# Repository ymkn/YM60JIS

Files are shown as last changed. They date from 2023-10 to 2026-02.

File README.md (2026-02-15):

# YM60JIS

A hot-swappable 60% mechanical keyboard PCB with Japanese (JIS) layout, powered by the RP2040 microcontroller. It is compatible with most Poker and GH60-style 60% keyboard cases.

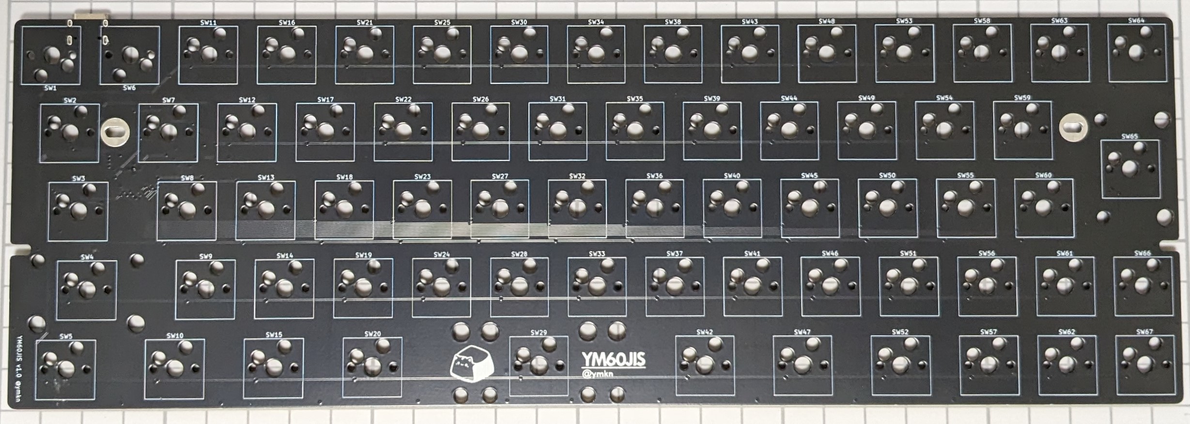
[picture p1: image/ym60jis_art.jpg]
YM60JIS Art


## Default Layout / Key Mapping

Customize your key mapping from the default shown below using the [Vial](https://get.vial.today/) configurator.

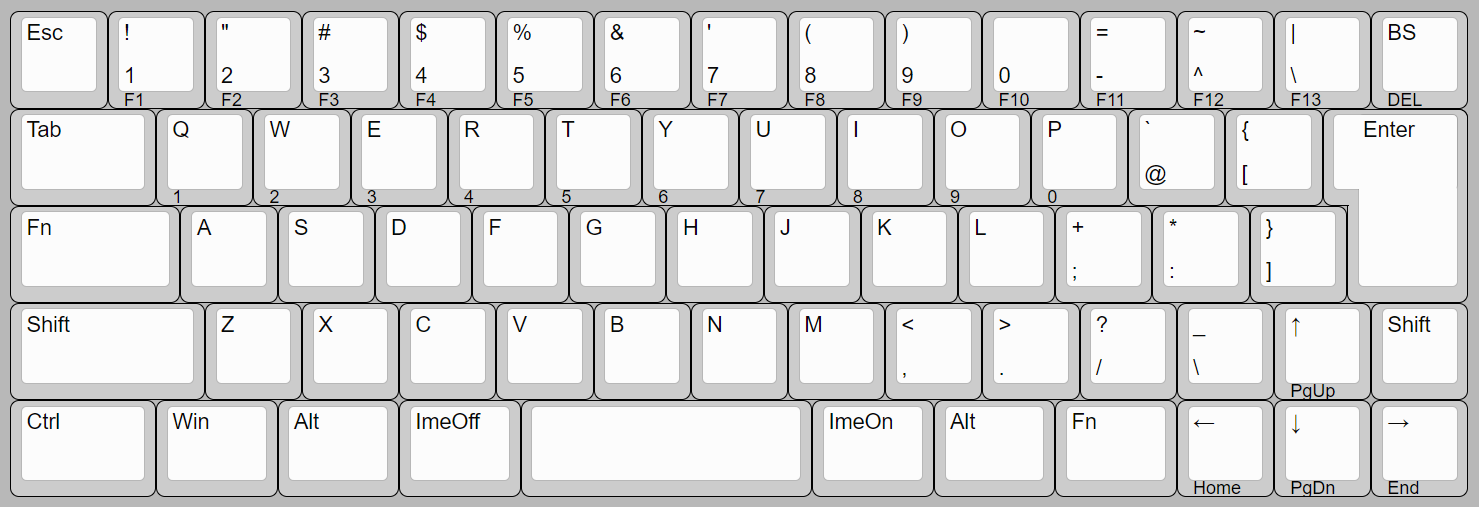
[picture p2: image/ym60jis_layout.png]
YM60JIS Layout


Supports 3u spacebar (requires 3u stabilizers) or 2.25u/2.75u spacebar with 2u stabilizers.

## Specification

- Supports Cherry MX-style switches
- USB Type-C connector (USB 2.0)
- Hot-swap sockets for mechanical switches
- Dimensions: 285 × 94.6 × 1.6 mm (W × H × D)
- Compatible with most 60% keyboard cases
  - Note: Center and right bottom mounting holes are not included

## Build Guide

See [doc/buildguide.md](doc/buildguide.md)

## LICENSE

This project is licensed under the MIT License, see the [LICENSE file](LICENSE) for details.

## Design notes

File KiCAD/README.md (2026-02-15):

# KiCAD source files

## Requirements

KiCAD 8.x or higher

## Dependencies

### Package Manager Libraries

Install the following library from KiCAD Package Manager:

- marbastlib (https://github.com/ebastler/marbastlib)
  - Install via the external ebastler KiCAD repository or from file

### External libraries

The following libraries are included as submodules:

- kleeb (https://github.com/crides/kleeb)
  - Components: rp2040-zero
- KiCAD_FootPrint (https://github.com/Salicylic-acid3/KiCAD_FootPrint)
  - Components: Keyswitch hole, stabilizer hole
- gh60 (https://github.com/komar007/gh60)
  - Components: Mounting hole

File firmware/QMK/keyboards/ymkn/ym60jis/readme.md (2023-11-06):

# ymkn/ym60jis

YM60JIS - A JIS layout 60% hot swappable custom mechanical keyboard PCB powered by RP2040.

* Keyboard Maintainer: [ymkn](https://github.com/ymkn)

Make example for this keyboard (after setting up your build environment):

    make ymkn/ym60jis:vial

Flashing example for this keyboard:

1. Enter the bootloader.
2. Simply copy ymkn_ym60jis_vial.uf2 to RPI_RP2 drive.

This keyboard supports [Vial](https://get.vial.today/) configurator.

## Bootloader

Enter the bootloader in 2 ways:

* **Bootmagic reset**: Hold down the key at (0,0) in the matrix (usually the top left key or Escape) and plug in the keyboard
* **Physical reset button**: Briefly press the button on the back of the PCB - some may have pads you must short instead

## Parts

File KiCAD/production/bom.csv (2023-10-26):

Designator | Footprint | Quantity | Value | LCSC Part #
BTN1 | SW_Push_1P1T_XKB_TS-1187A | 1 | TS-1187A-B-A-B
C1, C2 | 0402 | 2 | 10uF
C10, C13, C16, C17, C3, C4, C5, C6, C7, C8, C9 | 0402 | 11 | 100nF
C11, C12 | 0402 | 2 | 1uF
C14, C15 | 0402 | 2 | 20pF
D1, D10, D11, D12, D13, D14, D15, D16, D17, D18, D19, D2, D20, D21, D22, D23, D24, D25, D26, D27, D28, D29, D3, D30, D31, D32, D33, D34, D35, D36, D37, D38, D39, D4, D40, D41, D42, D43, D44, D45, D46, D47, D48, D49, D5, D50, D51, D52, D53, D54, D55, D56, D57, D58, D59, D6, D60, D61, D62, D63, D64, D65, D66, D67, D7, D8, D9 | D_SOD-123 | 67 | 1N4148W
J1 | USB_C_Receptacle_HRO_TYPE-C-31-M-12 | 1 | TYPE-C-31-M-12
R1, R3 | 0402 | 2 | 5.1K
R4, R5 | 0603 | 2 | 27
R6 | 0402 | 1 | 1KΩ
R7 | 0402 | 1 | 10kΩ
R8 | 0402 | 1 | 1K
SW1, SW11, SW12, SW13, SW14, SW16, SW17, SW18, SW19, SW21, SW22, SW23, SW24, SW25, SW26, SW27, SW28, SW30, SW31, SW32, SW33, SW34, SW35, SW36, SW37, SW38, SW39, SW40, SW41, SW43, SW44, SW45, SW46, SW48, SW49, SW50, SW51, SW53, SW54, SW55, SW56, SW57, SW58, SW59, SW6, SW60, SW61, SW62, SW66, SW67, SW7, SW8, SW9 | SW_Hotswap_Kailh_MX_1.00u | 53 | SW_Push
SW10, SW15, SW20, SW42, SW47, SW52 | SW_Hotswap_Kailh_MX_1.25u | 6 | SW_Push
SW2, SW5 | SW_Hotswap_Kailh_MX_1.50u | 2 | SW_Push
SW29 | SW_Hotswap_Kailh_MX_3.00u | 1 | Space
SW3 | SW_Hotswap_Kailh_MX_1.75u | 1 | SW_Push
SW4 | SW_Hotswap_Kailh_MX_2.00u | 1 | SW_Push
SW63 | SW_Hotswap_Kailh_MX_1.00u | 1 | Yen
SW64 | SW_Hotswap_Kailh_MX_1.00u | 1 | Backspace
SW65 | SW_Hotswap_Kailh_MX_ISOEnter | 1 | ISOEnter
U1 | SOT-23-3 | 1 | XC6206P332MR
U2 | SOT-363-6_2P2X1P35_ONS | 1 | SMF05CT1G
U3 | QFN-56-1EP_7x7mm_P0.4mm_EP3.2x3.2mm | 1 | RP2040
U4 | W25Q16JVUXIQ_WIN | 1 | W25Q16JVUXIQ
Y1 | Crystal_SMD_3225-4Pin_3.2x2.5mm | 1 | X322512MSB4SI

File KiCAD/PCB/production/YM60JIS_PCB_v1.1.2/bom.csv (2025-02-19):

Designator | Footprint | Quantity | Value | LCSC Part #
BTN1 | SW_Push_1P1T_XKB_TS-1187A | 1 | TS-1187A-B-A-B | C318884
C1, C2 | 0402 | 2 | 10uF | C15525
C10, C13, C16, C17, C3, C4, C5, C6, C7, C8, C9 | 0402 | 11 | 100nF | C1525
C11, C12 | 0402 | 2 | 1uF | C52923
C14, C15 | 0402 | 2 | 20pF | C1554
D1, D10, D11, D12, D13, D14, D15, D16, D17, D18, D19, D2, D20, D21, D22, D23, D24, D25, D26, D27, D28, D29, D3, D30, D31, D32, D33, D34, D35, D36, D37, D38, D39, D4, D40, D41, D42, D43, D44, D45, D46, D47, D48, D49, D5, D50, D51, D52, D53, D54, D55, D56, D57, D58, D59, D6, D60, D61, D62, D63, D64, D65, D66, D67, D7, D8, D9 | D_SOD-123 | 67 | 1N4148W | C81598
J1 | USB_C_Receptacle_HRO_TYPE-C-31-M-12 | 1 | TYPE-C-31-M-12 | C165948
R1, R3 | 0402 | 2 | 5.1K | C25905
R4, R5 | 0603 | 2 | 27 | C25190
R6 | 0402 | 1 | 1KΩ | C11702
R7 | 0402 | 1 | 10kΩ | C25744
R8 | 0402 | 1 | 1K | C11702
SW1, SW11, SW12, SW13, SW14, SW16, SW17, SW18, SW19, SW21, SW22, SW23, SW24, SW25, SW26, SW27, SW28, SW30, SW31, SW32, SW33, SW34, SW35, SW36, SW37, SW38, SW39, SW4, SW40, SW41, SW42, SW43, SW44, SW45, SW46, SW48, SW49, SW50, SW51, SW53, SW54, SW55, SW56, SW57, SW58, SW59, SW6, SW60, SW61, SW62, SW66, SW67, SW7, SW8, SW9 | SW_MX_HS_CPG151101S11_1u | 55 | SW_Push | C41430893
SW10, SW15, SW20, SW47, SW52 | SW_MX_HS_CPG151101S11_1.25u | 5 | SW_Push | C41430893
SW2, SW5 | SW_MX_HS_CPG151101S11_1.5u | 2 | SW_Push | C41430893
SW29 | SW_MX_HS_CPG151101S11_1u | 1 | Space | C41430893
SW3 | SW_MX_HS_CPG151101S11_1.75u | 1 | SW_Push | C41430893
SW63 | SW_MX_HS_CPG151101S11_1u | 1 | Yen | C41430893
SW64 | SW_MX_HS_CPG151101S11_1u | 1 | Backspace | C41430893
SW65 | SW_MX_HS_CPG151101S11_1u | 1 | ISOEnter | C41430893
U1 | SOT-23-3 | 1 | XC6206P332MR | C5446
U2 | SOT-363-6_2P2X1P35_ONS | 1 | SMF05CT1G | C15879
U3 | QFN-56-1EP_7x7mm_P0.4mm_EP3.2x3.2mm | 1 | RP2040 | C2040
U4 | W25Q16JVUXIQ_WIN | 1 | W25Q16JVUXIQ | C2843335
Y1 | Crystal_SMD_3225-4Pin_3.2x2.5mm | 1 | X322512MSB4SI | C9002

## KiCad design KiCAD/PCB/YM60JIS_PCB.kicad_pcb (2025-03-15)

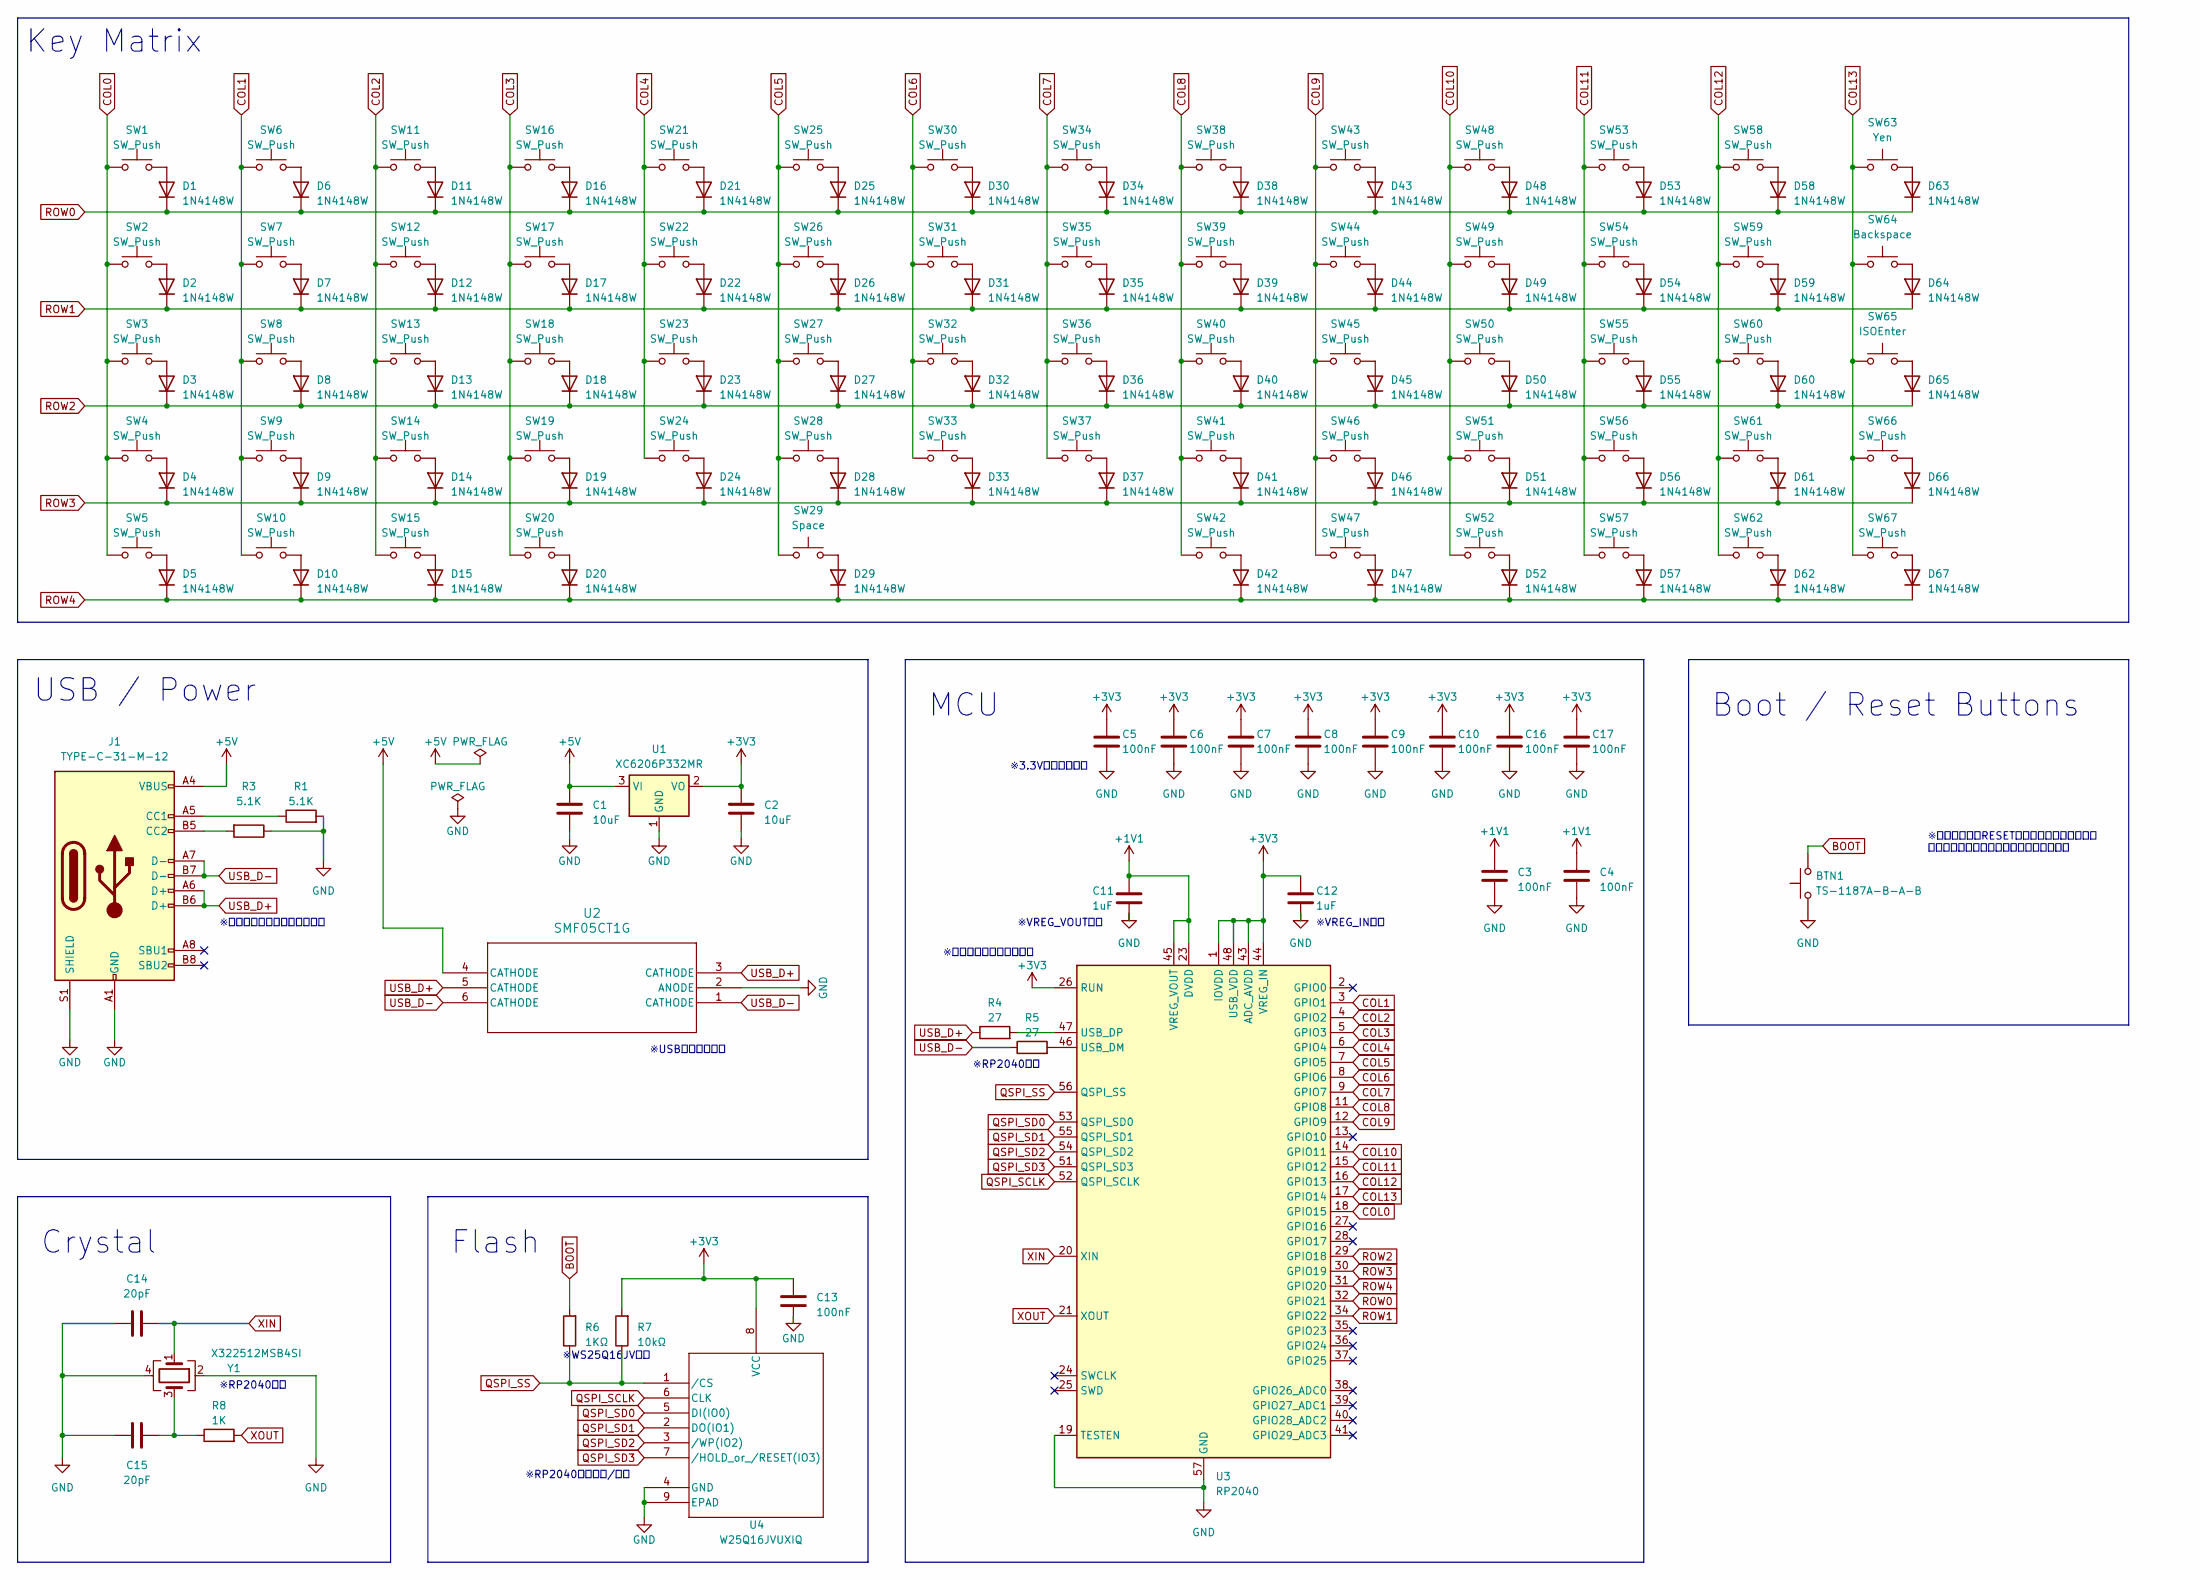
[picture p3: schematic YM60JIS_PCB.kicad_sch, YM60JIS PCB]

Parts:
BTN1: TS-1187A-B-A-B; SW_Push_1P1T_XKB_TS-1187A; JLCPCB Part # C318884
C1, C2: 10uF; C_0402_1005Metric; JLCPCB Part # C15525
C3, C4, C5, C6, C7, C8, C9, C10, C13, C16, C17: 100nF; C_0402_1005Metric; JLCPCB Part # C1525
C11, C12: 1uF; C_0402_1005Metric; JLCPCB Part # C52923
C14, C15: 20pF; C_0402_1005Metric; JLCPCB Part # C1554
D1, D2, D3, D4, D5, D6, D7, D8, D9, D10, D11, D12, D13, D14, D15, D16, D17, D18, D19, D20, D21, D22, D23, D24, D25, D26, D27, D28, D29, D30, D31, D32, D33, D34, D35, D36, D37, D38, D39, D40, D41, D42, D43, D44, D45, D46, D47, D48, D49, D50, D51, D52, D53, D54, D55, D56, D57, D58, D59, D60, D61, D62, D63, D64, D65, D66, D67: 1N4148W; D_SOD-123; JLCPCB Part # C81598
J1: TYPE-C-31-M-12; USB_C_Receptacle_HRO_TYPE-C-31-M-12; JLCPCB Part # C165948
R1, R3: 5.1K; R_0402_1005Metric; JLCPCB Part # C25905
R4, R5: 27; R_0603_1608Metric; JLCPCB Part # C25190
R6: 1KΩ; R_0402_1005Metric; JLCPCB Part # C11702
R7: 10kΩ; R_0402_1005Metric; JLCPCB Part # C25744
R8: 1K; R_0402_1005Metric; JLCPCB Part # C11702
SW1, SW4, SW6, SW7, SW8, SW9, SW11, SW12, SW13, SW14, SW16, SW17, SW18, SW19, SW21, SW22, SW23, SW24, SW25, SW26, SW27, SW28, SW30, SW31, SW32, SW33, SW34, SW35, SW36, SW37, SW38, SW39, SW40, SW41, SW42, SW43, SW44, SW45, SW46, SW48, SW49, SW50, SW51, SW53, SW54, SW55, SW56, SW57, SW58, SW59, SW60, SW61, SW62, SW66, SW67: SW_Push; SW_MX_HS_CPG151101S11_1u; JLCPCB Part # C41430893
SW2, SW5: SW_Push; SW_MX_HS_CPG151101S11_1.5u; JLCPCB Part # C41430893
SW3: SW_Push; SW_MX_HS_CPG151101S11_1.75u; JLCPCB Part # C41430893
SW10, SW15, SW20, SW47, SW52: SW_Push; SW_MX_HS_CPG151101S11_1.25u; JLCPCB Part # C41430893
SW29: Space; SW_MX_HS_CPG151101S11_1u; JLCPCB Part # C41430893
SW63: Yen; SW_MX_HS_CPG151101S11_1u; JLCPCB Part # C41430893
SW64: Backspace; SW_MX_HS_CPG151101S11_1u; JLCPCB Part # C41430893
SW65: ISOEnter; SW_MX_HS_CPG151101S11_1u; JLCPCB Part # C41430893
U1: XC6206P332MR; SOT-23-3; JLCPCB Part # C5446
U2: SMF05CT1G; SOT-363-6_2P2X1P35_ONS; JLCPCB Rotation Offset 180
U3: RP2040; QFN-56-1EP_7x7mm_P0.4mm_EP3.2x3.2mm; JLCPCB Part # C2040
U4: W25Q16JVUXIQ; W25Q16JVUXIQ_WIN; JLCPCB Rotation Offset 90
Y1: X322512MSB4SI; Crystal_SMD_3225-4Pin_3.2x2.5mm; JLCPCB Part # C9002

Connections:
+1V1: C3.1, C4.1, C11.1, U3.23 (DVDD), U3.45 (VREG_VOUT), U3.50 (DVDD)
+3V3: C2.1, C5.1, C6.1, C7.1, C8.1, C9.1, C10.1, C12.1, C13.1, C16.1, C17.1, R7.2, U1.2 (VO), U3.1 (IOVDD), U3.10 (IOVDD), U3.22 (IOVDD), U3.26 (RUN), U3.33 (IOVDD), U3.42 (IOVDD), U3.43 (ADC_AVDD), U3.44 (VREG_IN), U3.48 (USB_VDD), U3.49 (IOVDD), U4.8 (VCC)
+5V: C1.1, J1.A4 (VBUS), J1.A9 (VBUS), J1.B4 (VBUS), J1.B9 (VBUS), U1.3 (VI), U2.4 (CATHODE)
BOOT: BTN1.2, R6.2
COL0: SW1.1, SW2.1, SW3.1, SW4.1, SW5.1, U3.18 (GPIO15)
COL1: SW6.1, SW7.1, SW8.1, SW9.1, SW10.1, U3.3 (GPIO1)
COL2: SW11.1, SW12.1, SW13.1, SW14.1, SW15.1, U3.4 (GPIO2)
COL3: SW16.1, SW17.1, SW18.1, SW19.1, SW20.1, U3.5 (GPIO3)
COL4: SW21.1, SW22.1, SW23.1, SW24.1, U3.6 (GPIO4)
COL5: SW25.1, SW26.1, SW27.1, SW28.1, SW29.1, U3.7 (GPIO5)
COL6: SW30.1, SW31.1, SW32.1, SW33.1, U3.8 (GPIO6)
COL7: SW34.1, SW35.1, SW36.1, SW37.1, U3.9 (GPIO7)
COL8: SW38.1, SW39.1, SW40.1, SW41.1, SW42.1, U3.11 (GPIO8)
COL9: SW43.1, SW44.1, SW45.1, SW46.1, SW47.1, U3.12 (GPIO9)
COL10: SW48.1, SW49.1, SW50.1, SW51.1, SW52.1, U3.14 (GPIO11)
COL11: SW53.1, SW54.1, SW55.1, SW56.1, SW57.1, U3.15 (GPIO12)
COL12: SW58.1, SW59.1, SW60.1, SW61.1, SW62.1, U3.16 (GPIO13)
COL13: SW63.1, SW64.1, SW65.1, SW66.1, SW67.1, U3.17 (GPIO14)
GND: BTN1.1, C1.2, C2.2, C3.2, C4.2, C5.2, C6.2, C7.2, C8.2, C9.2, C10.2, C11.2, C12.2, C13.2, C14.1, C15.1, C16.2, C17.2, J1.A1 (GND), J1.A12 (GND), J1.B1 (GND), J1.B12 (GND), J1.S1 (SHIELD), R1.2, R3.1, U1.1 (GND), U2.2 (ANODE), U3.19 (TESTEN), U3.57 (GND), U4.4 (GND), U4.9 (EPAD), Y1.2, Y1.4
unnamed: C15.2, R8.1, Y1.3
unnamed: D1.2 (A), SW1.2
unnamed: D2.2 (A), SW2.2
unnamed: D3.2 (A), SW3.2
unnamed: D4.2 (A), SW4.2
unnamed: D5.2 (A), SW5.2
unnamed: D6.2 (A), SW6.2
unnamed: D7.2 (A), SW7.2
unnamed: D8.2 (A), SW8.2
unnamed: D9.2 (A), SW9.2
unnamed: D10.2 (A), SW10.2
unnamed: D11.2 (A), SW11.2
unnamed: D12.2 (A), SW12.2
unnamed: D13.2 (A), SW13.2
unnamed: D14.2 (A), SW14.2
unnamed: D15.2 (A), SW15.2
unnamed: D16.2 (A), SW16.2
unnamed: D17.2 (A), SW17.2
unnamed: D18.2 (A), SW18.2
unnamed: D19.2 (A), SW19.2
unnamed: D20.2 (A), SW20.2
unnamed: D21.2 (A), SW21.2
unnamed: D22.2 (A), SW22.2
unnamed: D23.2 (A), SW23.2
unnamed: D24.2 (A), SW24.2
unnamed: D25.2 (A), SW25.2
unnamed: D26.2 (A), SW26.2
unnamed: D27.2 (A), SW27.2
unnamed: D28.2 (A), SW28.2
unnamed: D29.2 (A), SW29.2
unnamed: D30.2 (A), SW30.2
unnamed: D31.2 (A), SW31.2
unnamed: D32.2 (A), SW32.2
unnamed: D33.2 (A), SW33.2
unnamed: D34.2 (A), SW34.2
unnamed: D35.2 (A), SW35.2
unnamed: D36.2 (A), SW36.2
unnamed: D37.2 (A), SW37.2
unnamed: D38.2 (A), SW38.2
unnamed: D39.2 (A), SW39.2
unnamed: D40.2 (A), SW40.2
unnamed: D41.2 (A), SW41.2
unnamed: D42.2 (A), SW42.2
unnamed: D43.2 (A), SW43.2
unnamed: D44.2 (A), SW44.2
unnamed: D45.2 (A), SW45.2
unnamed: D46.2 (A), SW46.2
unnamed: D47.2 (A), SW47.2
unnamed: D48.2 (A), SW48.2
unnamed: D49.2 (A), SW49.2
unnamed: D50.2 (A), SW50.2
unnamed: D51.2 (A), SW51.2
unnamed: D52.2 (A), SW52.2
unnamed: D53.2 (A), SW53.2
unnamed: D54.2 (A), SW54.2
unnamed: D55.2 (A), SW55.2
unnamed: D56.2 (A), SW56.2
unnamed: D57.2 (A), SW57.2
unnamed: D58.2 (A), SW58.2
unnamed: D59.2 (A), SW59.2
unnamed: D60.2 (A), SW60.2
unnamed: D61.2 (A), SW61.2
unnamed: D62.2 (A), SW62.2
unnamed: D63.2 (A), SW63.2
unnamed: D64.2 (A), SW64.2
unnamed: D65.2 (A), SW65.2
unnamed: D66.2 (A), SW66.2
unnamed: D67.2 (A), SW67.2
unnamed: J1.A5 (CC1), R1.1
unnamed: J1.B5 (CC2), R3.2
unnamed: R5.2, U3.46 (USB_DM)
unnamed: R4.2, U3.47 (USB_DP)
QSPI_SCLK: U3.52 (QSPI_SCLK), U4.6 (CLK)
QSPI_SD0: U3.53 (QSPI_SD0), U4.5 (DI(IO0))
QSPI_SD1: U3.55 (QSPI_SD1), U4.2 (DO(IO1))
QSPI_SD2: U3.54 (QSPI_SD2), U4.3 (/WP(IO2))
QSPI_SD3: U3.51 (QSPI_SD3), U4.7 (/HOLD_or_/RESET(IO3))
QSPI_SS: R6.1, R7.1, U3.56 (QSPI_SS), U4.1 (/CS)
ROW0: D1.1 (K), D6.1 (K), D11.1 (K), D16.1 (K), D21.1 (K), D25.1 (K), D30.1 (K), D34.1 (K), D38.1 (K), D43.1 (K), D48.1 (K), D53.1 (K), D58.1 (K), D63.1 (K), U3.32 (GPIO21)
ROW1: D2.1 (K), D7.1 (K), D12.1 (K), D17.1 (K), D22.1 (K), D26.1 (K), D31.1 (K), D35.1 (K), D39.1 (K), D44.1 (K), D49.1 (K), D54.1 (K), D59.1 (K), D64.1 (K), U3.34 (GPIO22)
ROW2: D3.1 (K), D8.1 (K), D13.1 (K), D18.1 (K), D23.1 (K), D27.1 (K), D32.1 (K), D36.1 (K), D40.1 (K), D45.1 (K), D50.1 (K), D55.1 (K), D60.1 (K), D65.1 (K), U3.29 (GPIO18)
ROW3: D4.1 (K), D9.1 (K), D14.1 (K), D19.1 (K), D24.1 (K), D28.1 (K), D33.1 (K), D37.1 (K), D41.1 (K), D46.1 (K), D51.1 (K), D56.1 (K), D61.1 (K), D66.1 (K), U3.30 (GPIO19)
ROW4: D5.1 (K), D10.1 (K), D15.1 (K), D20.1 (K), D29.1 (K), D42.1 (K), D47.1 (K), D52.1 (K), D57.1 (K), D62.1 (K), D67.1 (K), U3.31 (GPIO20)
USB_D+: J1.A6 (D+), J1.B6 (D+), R4.1, U2.3 (CATHODE), U2.5 (CATHODE)
USB_D-: J1.A7 (D-), J1.B7 (D-), R5.1, U2.1 (CATHODE), U2.6 (CATHODE)
XIN: C14.2, U3.20 (XIN), Y1.1
XOUT: R8.2, U3.21 (XOUT)

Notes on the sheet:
※RP2040近傍
Flash
Key Matrix
※リセットボタン実装無し
USB / Power
※WS25Q16JV近傍
※USBコネクタ近傍
※差動信号、配線長さ合わせる
※VREG_IN近傍
Boot / Reset Buttons
MCU
※3.3V電源ピン近傍
※RP2040近傍配置/直結
※VREG_VOUT近傍
Crystal
※以前はここにRESETボタンの回路があった。 基板スペースと費用の都合で削除した。

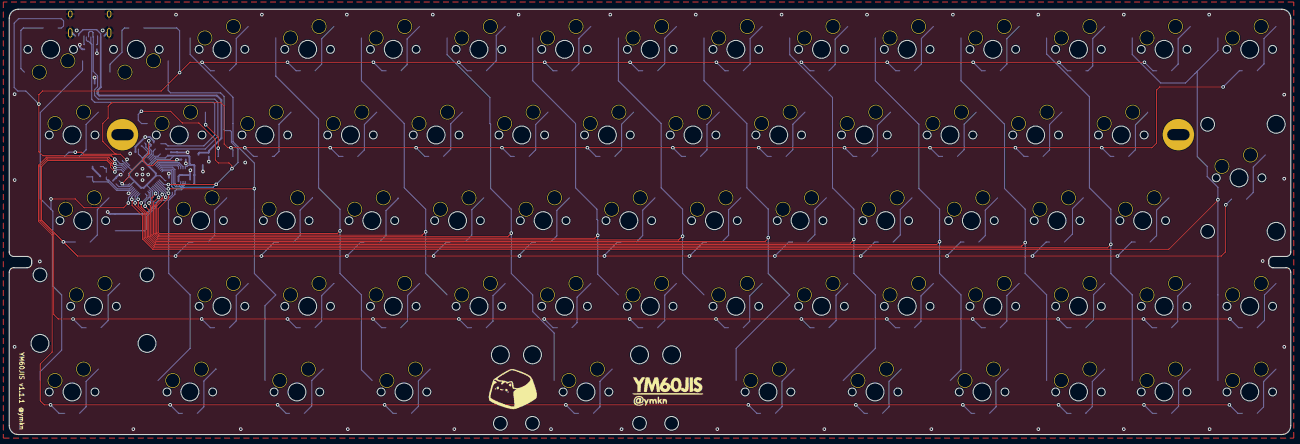
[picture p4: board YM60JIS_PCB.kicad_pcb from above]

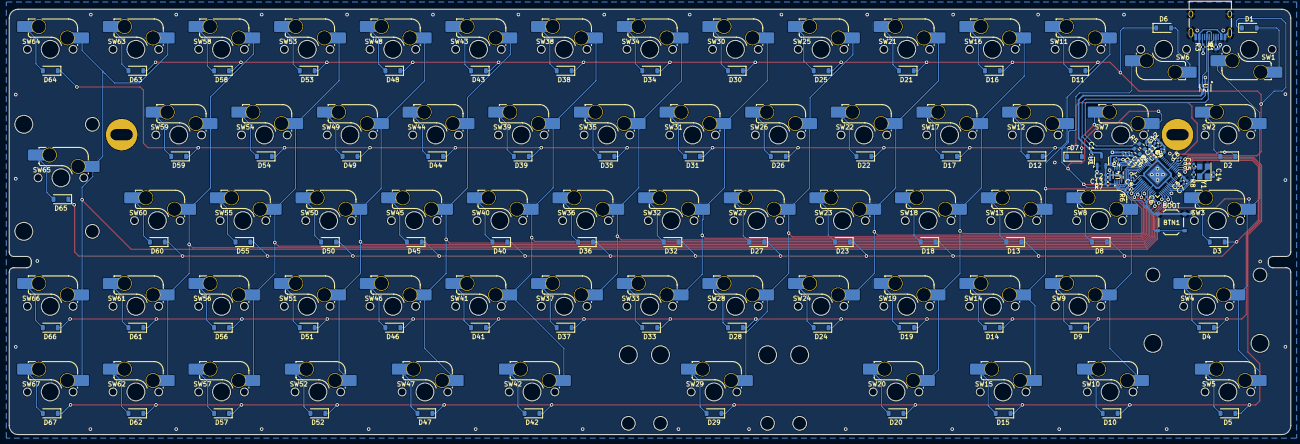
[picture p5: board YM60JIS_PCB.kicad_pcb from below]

Board: 2 copper layers, 285.1 x 94.6 mm, 165 parts (165 on the bottom side), 106 nets.

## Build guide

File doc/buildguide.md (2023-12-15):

# YM60JIS ビルドガイド

## 1. はじめに

本書は自作キーボード基板であるYM60JISのビルドガイドです。キーボードとして利用可能になるまでの手順を初心者向けに丁寧に記載したつもりですが、不明な個所などある場合は適時検索するなどして補ってください。

申し訳ないのですがYM60JIS固有でない一般のご質問にはお答えできません。各自お調べください。

**キーボード自作経験者向け：** 必要なことはCherry MX用スイッチソケットの調達とそのはんだ付けだけです。ファームウェアはQMKが書き込み済みで、キーマップ変更はVialに対応しています。これでわかればここから先を読む必要はありません。

## 2. 準備

### 2.1 内容物確認

YM60JISは本体となる基板とキースイッチ固定用のトッププレートのセットです。しかし、これだけではキーボードとして使うことができません。その他必要な部品を別途調達いただく必要があります。

|品目|数量|
|---|---|
|YM60JIS 基板|1|
|YM60JIS トッププレート|1|

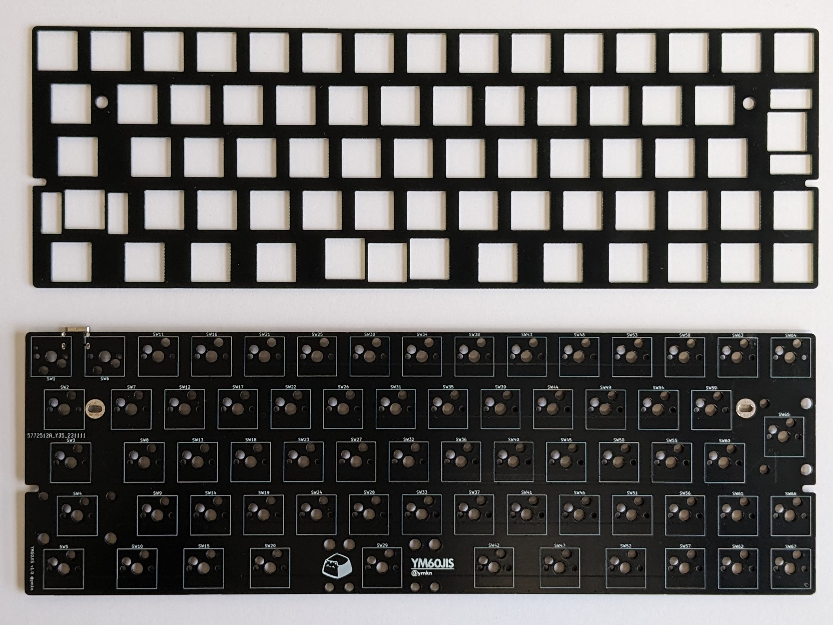
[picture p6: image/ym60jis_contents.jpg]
YM60JIS内容物


### 2.2 別途用意が必要な部品

下記部品は国内外の自作キーボード専門店や電子部品販売店などから別途調達してください。

|品目|数量|備考|
|---|---|---|
|MX互換キースイッチ|67|[Cherry MX](https://www.cherrymx.de/en/dev.html)もしくはその互換品|
|MX互換スイッチソケット|67|[Kailh PCB Socket CPG151101S11](https://www.kailhswitch.com/mechanical-keyboard-switches/box-switches/mechanical-keyboard-switches-kailh-pcb-socket.html)もしくはその互換品|
|MX互換キーキャップ|-|[Cherry MX](https://www.cherrymx.de/en/dev.html)もしくはその互換品|
|2uサイズPCBマウント型スタビライザー|2|幅の広いキーの押し下げを安定させる部品です。左ShiftキーとEnterキーに用います|
|2u or 3uサイズPCBマウント型スタビライザー|1|幅の広いキーの押し下げを安定させる部品です。スペースキーに用います。3uスタビライザーと3uスペースキーの組み合わせが推奨です。2uスタビライザーと2.75uスペースキーの組み合わせでも代用可能ですが、隙間が空きます|
|Poker互換60%サイズキーボードケース）|1|Poker互換、60%、GH60対応品、などと称して販売されているトップマウント型のケースが利用できます（※すべてのケースで完全な互換性を保証するものではありません）|

### キーキャップ選択の考え方

#### 日本語JISレイアウト対応のキーキャップについて

まず、日本語JISレイアウト向けの印字を持つ既製品のキーキャップセットは、ほぼ存在しません。

2023年11月現在での入手性の良い選択肢としてはサリチル酸さん作成の[Acid Caps JP](https://salicylic-acid3.hatenablog.com/entry/acid-caps-v3)シリーズと[Keychron社のJIS対応キーキャップセット](https://www.keychron.com/collections/iso-ansi-jis-keycaps)があります。

参考： [自作キーボードに使える日本語配列キーキャップ（2021年12月版） \- NinthSky Studio](https://ninthsky.hatenablog.com/entry/keycap_JP)

そのため大抵の場合は英語圏ANSI/ISOレイアウト向けのキーキャップセットを入手し、実際のキーとは異なる印字のキーキャップを付けることになります。

これらにはひらがなやカタカナが印字されているものもありますが、一部キーの記号位置などを見るとどれもJISレイアウトと異なり、あくまでANSI/ISOレイアウト向けの「飾り」でしかないことがわかります。

#### 必要なキーキャップとサイズ

必要なキーキャップとそのサイズは下図の通りです。キーのサイズは正方形のキーの幅を「1u」と呼称します。2uであれば1uの2倍の幅のキーであることを示します。幅は0.25u刻みで様々なサイズがあります。

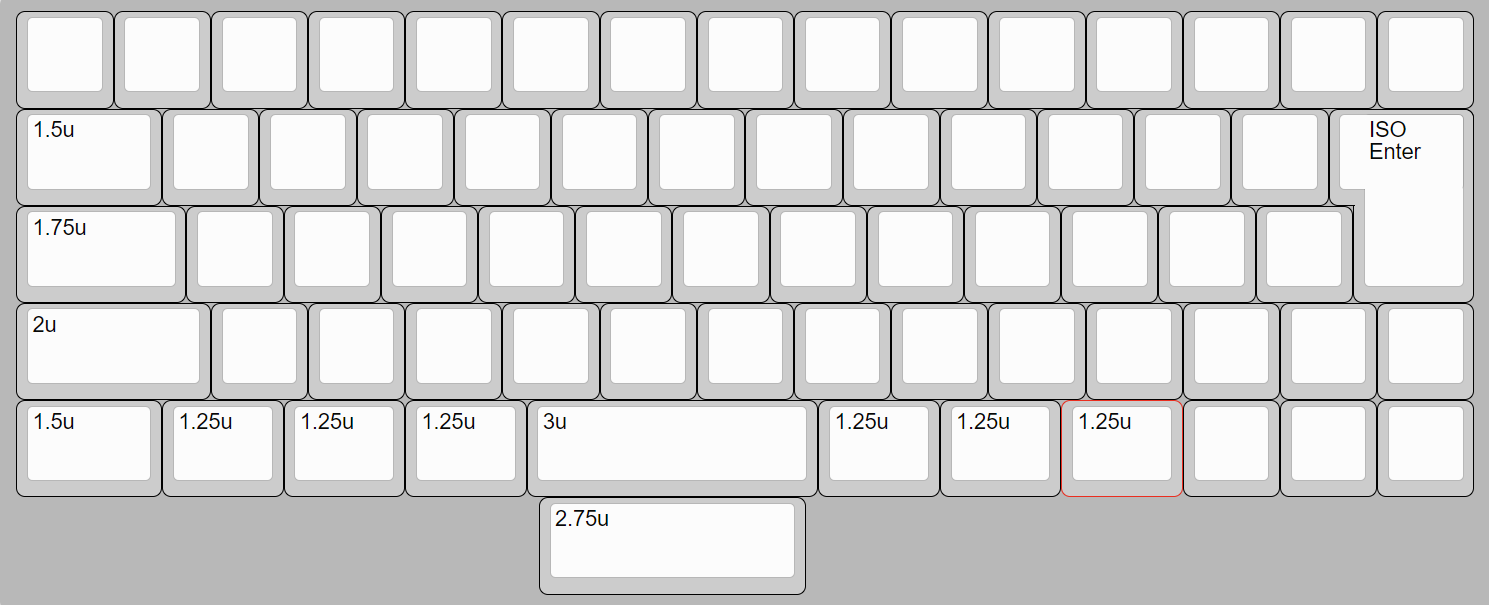
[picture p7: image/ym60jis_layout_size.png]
レイアウト


このうち、標準的なANSI/ISOレイアウト向けのキーキャップセットに含まれていないか、オプション扱いであることが多い注意すべきキーは次の通りです。オプションを購入するか、同じサイズの別の印字のキーキャップで代替してください。

|行|サイズ|初期レイアウトの対応キー名|
|---|---|---|
|R1|1u|Backspaceキー
|R2/3|ISO Enter|Enterキー|
|R4|2u|左Shiftキー|
|R4|1u|「ろ」の位置のキー|
|R4|1u|右Shiftキー|
|R5|1.25u|無変換、変換、Fn|
|R5|3u|スペースキー|

スペースキーは3uが推奨ですが、3uのスペースキーを用意できない場合は2.75uや2.25uでも代用できます（ただし左右に隙間が空きます）。

### 2.3 道具

|品目|数量|備考|
|---|---|---|
|はんだごて、はんだ|1|スイッチソケットのはんだ付けに用います。はんだごては調温機能付きのものを、はんだは鉛入りのものを推奨します|
|ピンセット|1|スイッチソケットのはんだ付けの際にあると便利です|
|ねじ回し（プラス）|1|基板をケースに固定する際に用います|

## 3. 組み立て

### 3.1 スイッチソケットのはんだ付け

スイッチソケットは基板の裏面（ICチップ等が実装されている面）に取り付けます。L字状のガイドが白線でキー数分印刷されていますので、そのすべてにスイッチソケットをはんだ付けします。

ICチップ近辺のソケットをはんだ付けする際は、はんだごてで電子部品をを焼いてしまわないように気を付けてください。

すべてのスイッチソケットが基板に密着しており、ソケット両端とも漏れなくはんだ付けされているか確認してください。基板から浮いていたり、はんだ付けができていないとキースイッチの動作不良の原因になります。

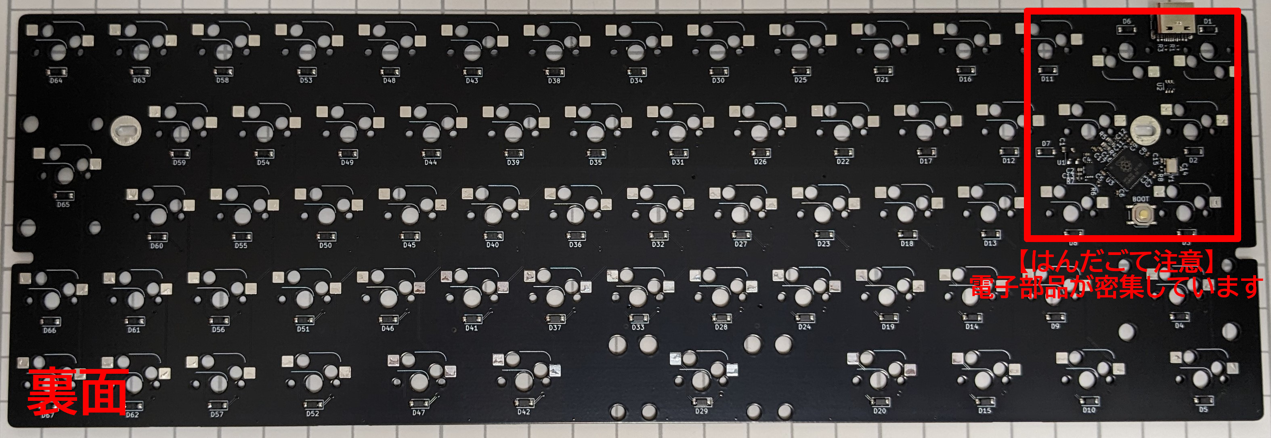
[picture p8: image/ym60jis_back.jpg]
YM60JIS裏面


> [!CAUTION]
> 右上の2つだけ、スイッチソケットの向きが逆になっているので注意してください！

### 3.2 スタビライザーの取り付け

スタビライザーは基板の表面（ロゴが印刷されている面）に取り付けます。

左ShiftキーとEnterキーに2uサイズを、スペースキーに3uサイズ（2.75u以下のキーを代用する場合は2uサイズ）のスタビライザーを取り付けます。取り付け方はスタビライザーごとに異なりますが、一般には大きい穴の方にツメを引っかけ、小さい穴の方にプッシュピンを差し込む、もしくはネジ留めを行います。

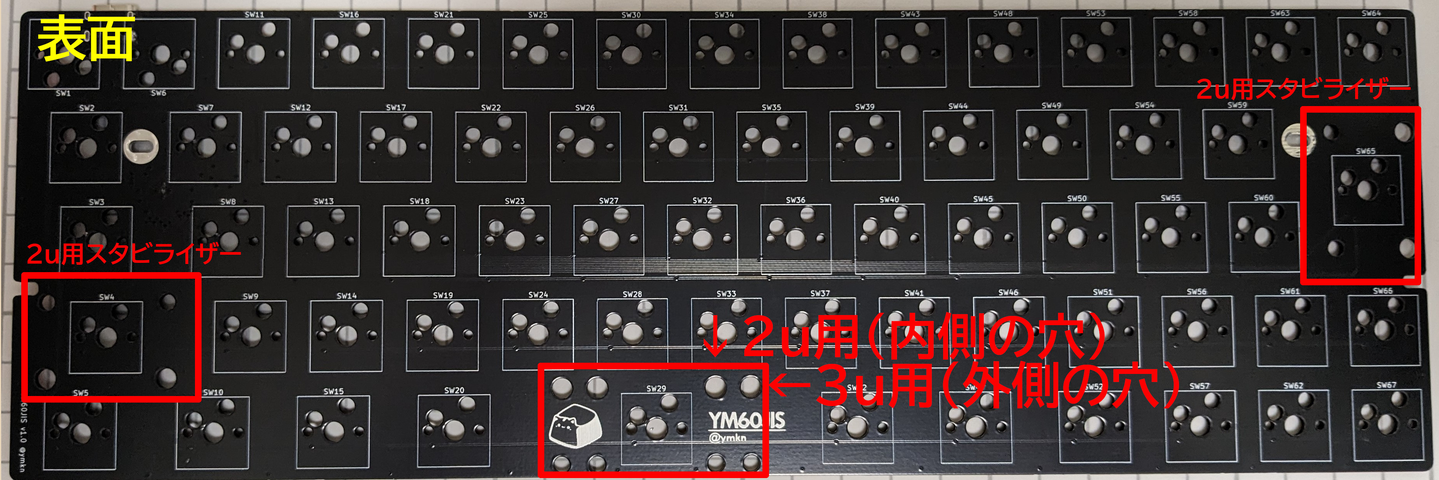
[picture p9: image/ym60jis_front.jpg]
YM60JIS表面


### 3.3 スイッチの取り付け

キースイッチはトッププレートを通して基板のソケットに差し込みます。すべてのキースイッチを一度に取り付けてしまうと基板に差し込むのが大変なので、まずトッププレートの四隅にキースイッチを取り付けて基板に差し込み、その後残りのスイッチを取り付けていくのがおすすめです。

### 3.4 ケースへの取り付け

Poker互換ケースにはネジ穴が6つほどあることが多いですが、本基板で利用できるのはそのうち4つのみとなります（中央と右下のネジ穴は使えません）。また、各ケース微妙にネジ穴やUSBコネクタ用穴の位置が異なるため位置が合わないことがありますが、その場合は留められる穴だけネジ留めしておけば問題ありません。

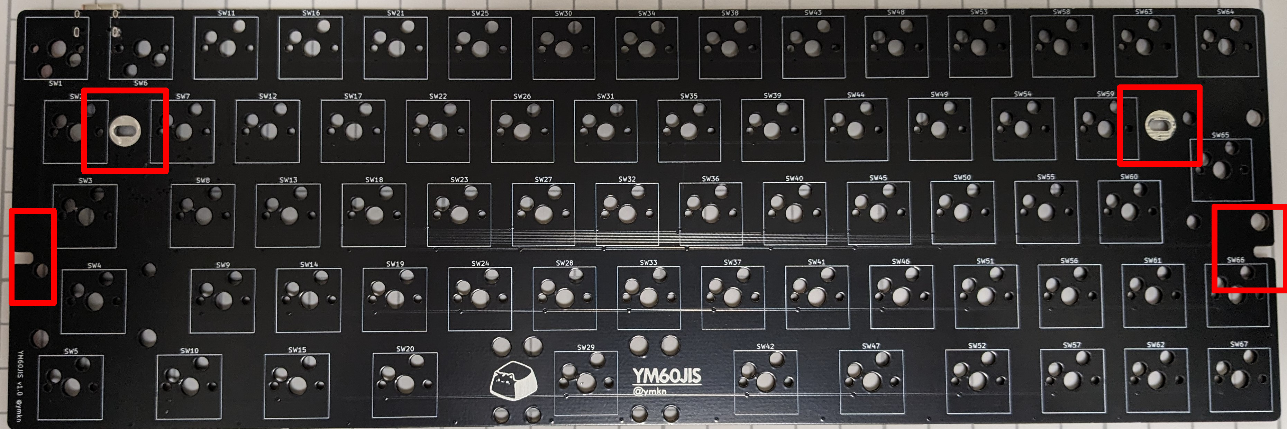
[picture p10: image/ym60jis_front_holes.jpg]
YM60JISネジ穴


また、一部のプラ製ケースなどでは構造が基板底面近くまでせり出しているものがあります。本基板はスイッチソケット分の厚みが基板底面から1.8mm程度ありますので、そのような構造と干渉することがあります。ケース側を加工するか、長めのネジに交換するなどの対応をしてください。

基板をケースに取り付けられれば完成です！

## 4. 使用

## 4.1 コンピュータとの接続

お使いのコンピュータのUSB 2.0に対応したUSBコネクタと接続してください。即時利用できるはずです。

## 4.2 キーマップのカスタマイズ

本キーボードは[Vial](https://get.vial.today/)というキーマップ変更ツールに対応しています。Vialの詳しい使いかたはVialのドキュメントや世間の情報を参考にしてください。

### 漢字キー（日本語入力On/Off用のキー）について

本キーボードの初期レイアウトに漢字キーの割り当てはありません。その代わり、スペースキーの左側のキーをImeOffキーに、右側のキーをImeOnキーに割り当てています。ImeOnキーとImeOffキーはWindows 10 1903以降でMicrosoft IMEを使用している場合に利用可能です。漢字キーが必要な場合はレイアウトをカスタマイズして任意のキーに割り当ててください。

参考： [キーボード日本 \- ImeOn / ImeOff の実装 \| Microsoft Learn](https://learn.microsoft.com/ja-jp/windows-hardware/design/component-guidelines/keyboard-japan-ime)

## 5. その他

### 5.1 ブートモードの入り方

RP2040のブートモードに入るには、左上のキー（Escキー）を押しながらUSBケーブルを接続します。

もしくは、基板裏面のBOOTスイッチを押しながらUSBケーブルを接続します。

### 5.2 ファームウェアのありか

本リポジトリ内で公開しています。

https://github.com/ymkn/YM60JIS/blob/main/firmware/QMK/ymkn_ym60jis_vial.uf2

### 5.3 ソースコード/設計データのありか

本リポジトリ内で公開しています。MITライセンスです。

https://github.com/ymkn/YM60JIS

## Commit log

2023-10-26 first production
    [YM60JIS.kicad_pcb, YM60JIS.kicad_sch, bom.csv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]
2023-10-28 JLCPCGのPCBAで向きが誤っている部品にJLCPCB Rotation Offset指示を追加
    [YM60JIS.kicad_pcb, YM60JIS.kicad_sch, bom.csv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]
2023-11-06 READMEを拡充
2023-11-06 PRKファームウェアのコードを追加（動作確認用）
2023-11-06 QMKファームウェアを追加
2023-11-10 デフォルトキーマップを変更（無変換・変換キーのHoldを削除）
2023-11-10 プレートの追加
    [YM60JIS_Plate.kicad_pcb, bom.csv, designators.csv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]
2023-11-10 PCBの設計データリネームとフォルダ移動
    [YM60JIS_PCB .kicad_pcb, YM60JIS_PCB .kicad_sch, bom.csv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]
2023-11-10 Plateにlibは不要のため削除
2023-11-12 スペースキー左右の初期レイアウトにImeOn/Offを設定
2023-11-26 ビルドガイドの追加
2023-12-05 ビルドガイド修正
2023-12-06 ファームウェアのVIDとPIDが誤っていたのを修正
2023-12-06 ファームウェアのVID/PIDの更新
2023-12-13 BOOTモードの入り方のキー誤りを修正
2023-12-15 スイッチソケット向き注意書き追加
2024-01-01 依存ライブラリをsubmoduleから参照するように変更
2024-01-01 ライブラリの参照先をsubmodulesに変更
    [YM60JIS_PCB .kicad_pcb, YM60JIS_PCB .kicad_sch]
2024-01-01 submodulesのパスを変更
    [YM60JIS_Plate.kicad_pcb]
2024-01-02 マウント穴の位置をGH60と同じ位置に調整
    [YM60JIS_PCB .kicad_pcb]
2024-01-07 PlateのライブラリパスをPCBと同様にsubmoduleへ変更、穴位置も微調整
    [YM60JIS_PCB.kicad_pcb, YM60JIS_PCB.kicad_sch, YM60JIS_Plate.kicad_pcb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]
2024-01-17 左右のネジ穴を拡張、背面のテキストを除去
    [YM60JIS_Plate.kicad_pcb]
2025-02-09 READMEの英語を改善
2025-02-09 v1.1およびv1.1.1の追加
    [YM60JIS_PCB.kicad_pcb, YM60JIS_PCB.kicad_sch, bom.csv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]
2025-02-19 部品指定の誤りを修正
    [YM60JIS_PCB.kicad_pcb, YM60JIS_PCB.kicad_sch, bom.csv]
2025-03-15 COL列配線を微調整
    [YM60JIS_PCB.kicad_pcb, bom.csv, designators.csv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]
2025-03-15 PlateのプロジェクトをKiCAD8形式に変更
    [YM60JIS_Plate.kicad_pcb]
2026-02-15 ファームウェア最新化（2026/2/15時点vial-qmk取り込み）
